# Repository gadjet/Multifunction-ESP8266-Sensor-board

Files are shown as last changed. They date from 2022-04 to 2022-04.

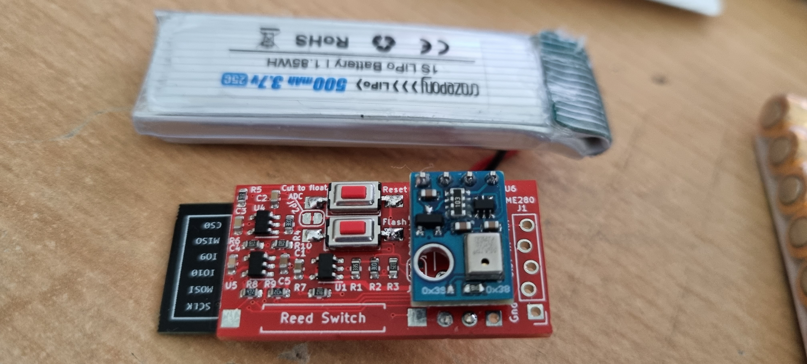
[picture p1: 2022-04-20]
Version 4 with AHT10 Sensor.jpg

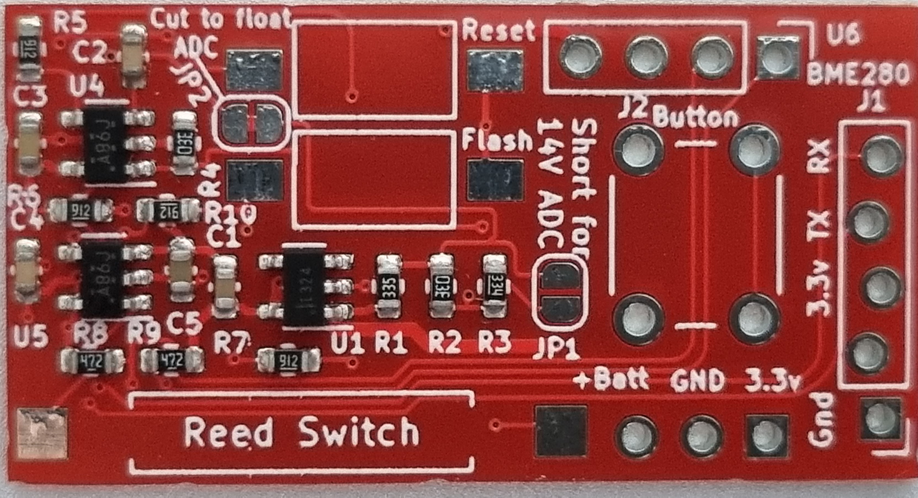
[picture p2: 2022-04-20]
Version 4 PCB.jpg

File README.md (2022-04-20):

# Multifunction-ESP8266-Sensor-board
AKA Wireless window/door sensor version 4

This is another in the series of wireless Window/Door sensor boards I've been designing, yes I know I've already published version 5 but this is the design before that one, I considered it a bit of a failure really because I was aiming for lower power consumption than version 3 but because I misread the LDO's specification I ended up using more power, around 85uA against the 20uA for version 3.

This board is different to version 3 because as well as being able to be triggered with a reed switch it also has the ability to have a button added to trigger the transmission instead or as well as the reed switch (doorbell?) also there is the mounting position to add an I2C sensor board such as the BME280 or AHT10 or even an OLED display or both.

The other key difference is the ability to power the ESP8266 from a Li-Ion cell (4.2v) via the LDO or directly from a 3V source such as a couple of AA cells, this bypasses the LDO completely.

There are also a couple of jumpers on the PCB for configuring the ADC input: -
 - JP1 is open circuit by default and when shorted out it modifies the voltage divider to increase the max ADC voltage to 14V, the LDO is capable of 16V input.
 - JP2 is short circuit by default and when open circuited it disconnects the ADC input from the voltage divider, used to monitor supply voltage, allowing the internal VCCread() function to be used in the code when powering the circuit directly from the 3V input.

Improvements that can be made
Use the previous LDO (HT7333) which uses less quiescent current
Power the Sensor board from a pin of the ESP so it's only powered up when used

              *********  PLEASE NOTE  *********

Some I2C boards do not have the same pinout so please check your I2C board has the same pinout as the PCB before using it.

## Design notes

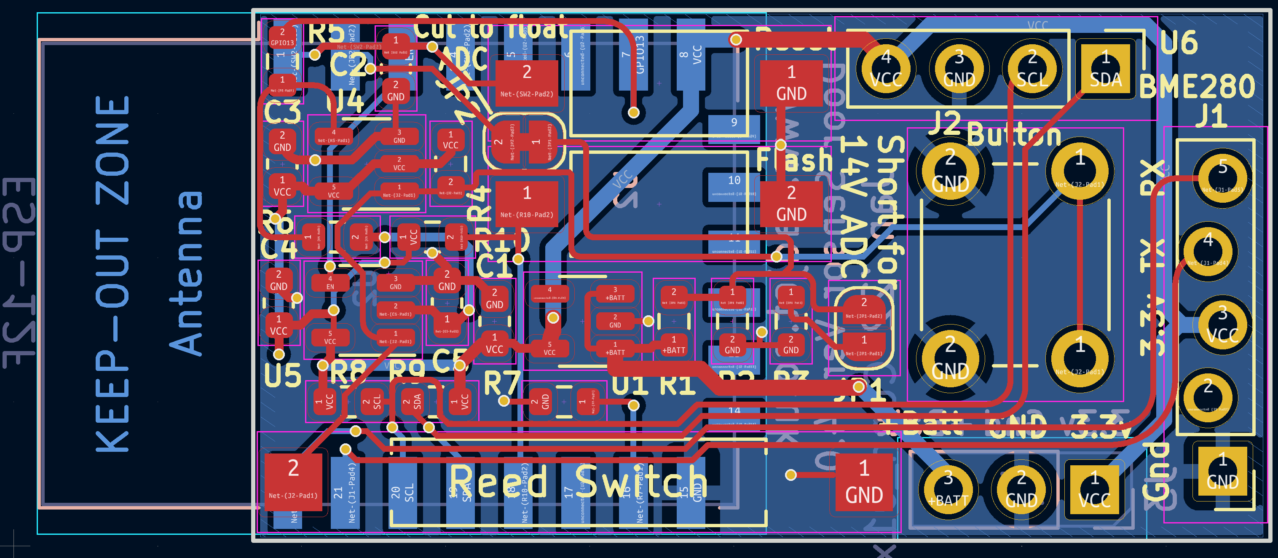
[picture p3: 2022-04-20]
Version 4 Kicad PCB layout.png

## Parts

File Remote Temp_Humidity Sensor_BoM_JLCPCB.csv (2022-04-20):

Comment | Designator | Footprint | LCSC part number
2.2uF | C1 | Capacitor_SMD:C_0603_1608Metric | C71000
100nF | C2, C3, C4 | Capacitor_SMD:C_0603_1608Metric | C14663
1uF | C5 | Capacitor_SMD:C_0603_1608Metric | C15849
3M3 | R1 | Resistor_SMD:R_0603_1608Metric | C39227
1M05 | R2, R4 | Resistor_SMD:R_0603_1608Metric | C247058
330k | R3 | Resistor_SMD:R_0603_1608Metric | C23137
10K | R5, R6, R7, R10 | Resistor_SMD:R_0603_1608Metric | C25804
4K7 | R8, R9 | Resistor_SMD:R_0603_1608Metric | C705902
SPX3819M5-L-3-3 | U1 | Package_TO_SOT_SMD:SOT-23-5 | C9055
74AHC1G86 | U4, U5 | Package_TO_SOT_SMD:SOT-23-5 | C460494

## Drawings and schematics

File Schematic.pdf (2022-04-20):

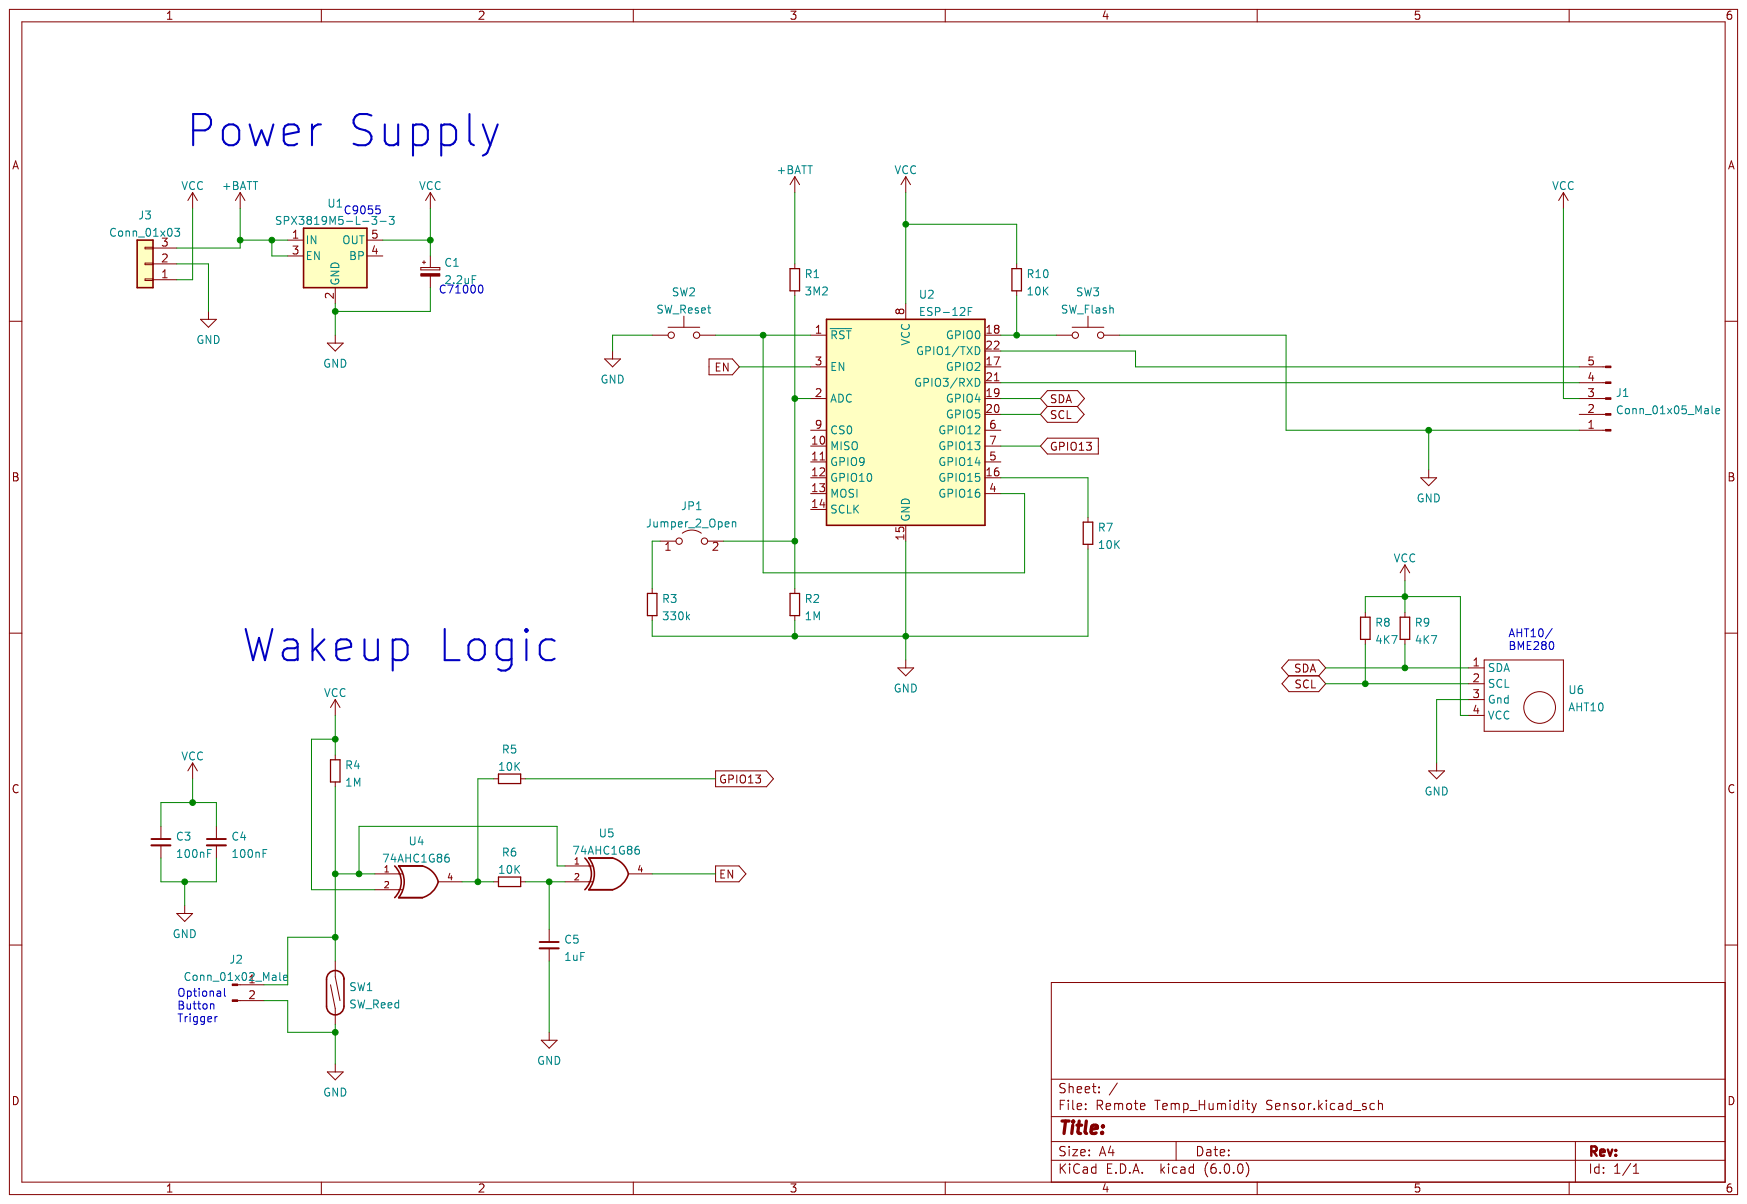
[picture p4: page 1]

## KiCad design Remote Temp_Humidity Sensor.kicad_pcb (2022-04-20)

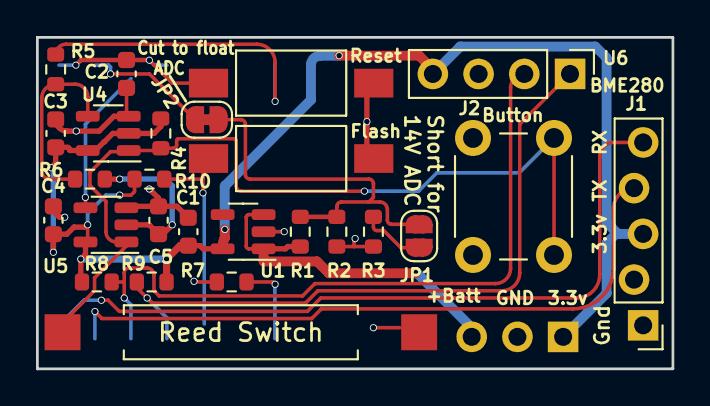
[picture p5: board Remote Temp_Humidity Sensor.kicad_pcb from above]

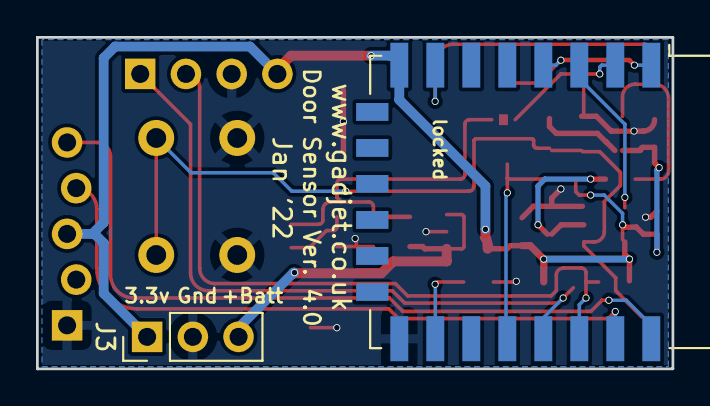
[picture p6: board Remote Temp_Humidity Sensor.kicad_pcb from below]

Board: 2 copper layers, 35.3 x 18.4 mm, 28 parts (2 on the bottom side), 18 nets.

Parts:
C1: 2.2uF; C_0603_1608Metric
C2, C3, C4: 100nF; C_0603_1608Metric
C5: 1uF; C_0603_1608Metric
Flash: SW_Flash; SW_SPST_FSMSM
J1: Conn_01x05_Male; PinHeader_1x05_P2.54mm_Vertical
J2: Conn_01x02_Male; SW_PUSH_6mm_H7.3mm
J3: Conn_01x03; PinHeader_1x03_P2.54mm_Vertical
JP1: Jumper_2_Open; SolderJumper-2_P1.3mm_Open_RoundedPad1.0x1.5mm
JP2: SolderJumper_2_Bridged; SolderJumper-2_P1.3mm_Bridged_RoundedPad1.0x1.5mm
R1: 3M3; R_0603_1608Metric
R2, R4: 1M05; R_0603_1608Metric
R3: 330k; R_0603_1608Metric
R5, R6, R7, R10: 10K; R_0603_1608Metric
R8, R9: 4K7; R_0603_1608Metric
Reed Switch: SW_Reed; SW_SPST_REED_CT10-XXXX-G2
Reset: SW_Reset; SW_SPST_FSMSM
U1: SPX3819M5-L-3-3; SOT-23-5
U4, U5: 74AHC1G86; SOT-23-5
U6: AHT10; PinHeader_1x04_P2.54mm_Vertical
locked: ESP-12F; ESP-12E

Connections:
+BATT: J3.3, R1.1, U1.1 (IN), U1.3 (EN)
EN: U5.4, locked.3 (EN)
GND: C1.2, C2.2, C3.2, C4.2, C5.2, Flash.2, J1.1, J2.2, J3.2, R2.2, R3.2, R7.2, Reed Switch.1, Reset.1, U1.2 (GND), U4.3 (GND), U5.3 (GND), U6.3 (Gnd), locked.15 (GND)
GPIO13: R5.2, locked.7 (GPIO13)
unnamed: C5.1, R6.2, U5.2
unnamed: J1.4, locked.21 (GPIO3/RXD)
unnamed: J1.5, locked.22 (GPIO1/TXD)
unnamed: J2.1, R4.2, Reed Switch.2, U4.1, U5.1
unnamed: JP1.1 (A), R3.1
unnamed: JP1.2 (B), JP2.1 (A), R1.2, R2.1
unnamed: JP2.2 (B), locked.2 (ADC)
unnamed: R5.1, R6.1, U4.4
unnamed: R7.1, locked.16 (GPIO15)
unnamed: Flash.1, R10.2, locked.18 (GPIO0)
unnamed: C2.1, Reset.2, locked.1 (~RST), locked.4 (GPIO16)
SCL: R8.2, U6.2 (SCL), locked.20 (GPIO5)
SDA: R9.2, U6.1 (SDA), locked.19 (GPIO4)
VCC: C1.1, C3.1, C4.1, J1.3, J3.1, R4.1, R8.1, R9.1, R10.1, U1.5 (OUT), U4.2, U4.5 (VCC), U5.5 (VCC), U6.4 (VCC), locked.8 (VCC)

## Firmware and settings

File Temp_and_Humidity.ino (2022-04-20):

/* This code is made up from otherpeoples code I found on the internet and adapted for my use
This code sends temp and humidity every 15 minutes
*/
#include<ESP8266WiFi.h>
#include<espnow.h>
#include <Adafruit_AHT10.h>
 Adafruit_AHT10 aht;
#include <DallasTemperature.h>

// I used two receivers therefore there's two IP addresses
uint8_t bridgeAddress1[] = {0x11, 0x11, 0x11, 0x11, 0x11, 0x11};   //please update this with the MAC address of your ESP-NOW TO MQTT brigde
//uint8_t bridgeAddress2[] = {0xXX, 0xXX, 0xXX, 0xXX, 0xXX, 0xXX};   //please update this with the MAC address of your ESP-NOW TO MQTT brigde

// Set your Board ID (
#define BOARD_ID 12

const int reedSwitch = 13;

// Structure example to send data
// Must match the receiver structure
typedef struct struct_message {
  int id;
  char state[7];
  int vBatt;
  float Temp;
  float Humidity;
} struct_message;

// Create a struct_message called test to store variables to be sent
struct_message myData;

// Callback when data is sent (I removed the serial prints to save power)
void OnDataSent(uint8_t *mac_addr, uint8_t sendStatus) {
  /* Serial.print("\r\nLast Packet Send Status: ");
    if (sendStatus == 0){
     Serial.println("Delivery success");
    }
    else{
     Serial.println("Delivery fail");
    }
  */
}

void setup() {
aht.begin();
  
  // Init Serial Monitor
  //Serial.begin(115200);
  // initialize the reed switch pin as an input:
  pinMode(reedSwitch, INPUT);
  // initialize the wakeup pin as an input:
  pinMode(16, WAKEUP_PULLUP);
  // Set device as a Wi-Fi Station
  WiFi.mode(WIFI_STA);
  WiFi.disconnect();

  // Init ESP-NOW
  if (esp_now_init() != 0) {
    //Serial.println("Error initializing ESP-NOW");
    return;
  }
  // Set ESP-NOW role
  esp_now_set_self_role(ESP_NOW_ROLE_CONTROLLER);

  // Once ESPNow is successfully init, we will register for Send CB to
  // get the status of Trasnmitted packet
  esp_now_register_send_cb(OnDataSent);

  // Register peer(I used two receivers)
  esp_now_add_peer(bridgeAddress1, ESP_NOW_ROLE_SLAVE, 1, NULL, 0);
  //esp_now_add_peer(bridgeAddress2, ESP_NOW_ROLE_SLAVE, 2, NULL, 0);
}


void loop() {
sensors_event_t humidity, temp;
  aht.getEvent(&humidity, &temp);// populate temp and humidity objects with fresh data
  // Set values to send
  myData.id = BOARD_ID;
  // Read the state of the reed switch and send open or closed
  if (digitalRead(reedSwitch) == HIGH) {
    strcpy(myData.state, "Closed");
  }
  else {
    strcpy(myData.state, "Open");
  }
  
  myData.vBatt = (analogRead(A0) * 4.2 * 10 / 1023);
  myData.Humidity = humidity.relative_humidity; //temp.temperature;// populate temp and humidity objects with fresh data
  myData.Temp = temp.temperature;
  // Send message via ESP-NOW
  esp_now_send(0, (uint8_t *) &myData, sizeof(myData));
  ESP.deepSleep(900e6); //15 Min's sleep
  delay(200);
}

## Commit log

2022-04-20 Add files via upload
    Images of the PCB
2022-04-20 Add files via upload
    PDF of the Schematic diagram
2022-04-20 Add files via upload
    KiCAD PCB layout
2022-04-20 Add files via upload
    KiCAD files
    [Remote Temp_Humidity Sensor.kicad_pcb, Remote Temp_Humidity Sensor.kicad_sch]
2022-04-20 Add files via upload
    Production Gerber files
2022-04-20 Add files via upload
    JLCPCB BOM file
    [Remote Temp_Humidity Sensor_BoM_JLCPCB.csv]
2022-04-20 Add files via upload
    JLCPCB Component position files
    [Remote Temp_Humidity Sensor-top-pos.csv]
2022-04-20 Update README.md
    Added Improvements details and I2C connection warning
